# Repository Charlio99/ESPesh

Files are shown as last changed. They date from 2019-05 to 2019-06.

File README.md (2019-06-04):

# ESPesh







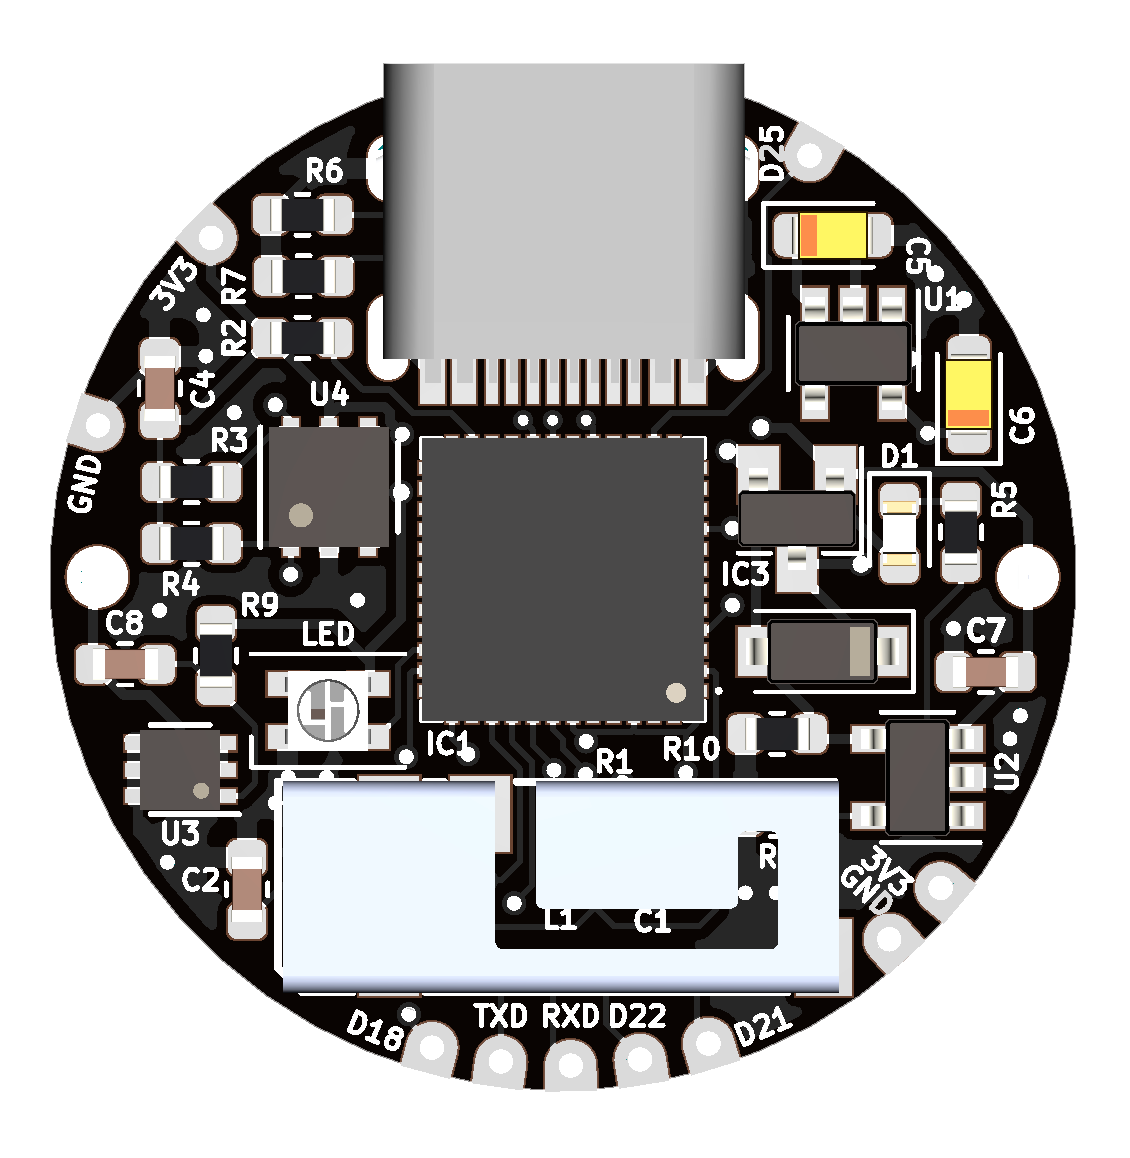
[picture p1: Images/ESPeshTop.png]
ESPesh


ESPesh is a super tiny board designed for IoT applications.
My plan is to use it as a BLE Mesh for IoT sensors and switches, because with BLE the power consumption is less than 1mA.

# Features

  - ESP32-PICO-D4
  - Low power design (LDO, removed unnecessary components)
  - Only one inch PCB
  - USB C (only for power, not programming)
  - LiPO battery (with charger and voltage protections)
  - Some GPIOs exposed (I2C included)

### BOM

I mainly use JLCPCB and LCSC for PCB and components.

| Component | Quantity | Link | Price |
| --- | --- | --- | --- |
| ESP32-PICO-D4 | 1 | https://lcsc.com/product-detail/Others_Espressif-Systems-ESP32-PICO-D4_C193707.html | $4.34 |
| PRO-OB-440 | 1 | https://www.digikey.es/product-detail/es/proant-ab/PRO-OB-440/1532-1001-1-ND/4895684 | $0.95 |
| LIR2450 | 1 | https://es.aliexpress.com/item/32853897751.html | $2.76 |
| 0.1uF | 3 | https://lcsc.com/product-detail/Multilayer-Ceramic-Capacitors-MLCC-SMD-SMT_SAMSUNG_CL10B104KA8NNNC_100nF-104-10-25V_C1590.html | $0.29 |
| 2.7pF | 1 | https://lcsc.com/product-detail/Multilayer-Ceramic-Capacitors-MLCC-SMD-SMT_SAMSUNG_CL10C2R7CB8NNNC_2-7pF-2R7-0-25pF-50V_C16149.html | $0.61 |
| 4.7pF | 1 | https://lcsc.com/product-detail/Multilayer-Ceramic-Capacitors-MLCC-SMD-SMT_SAMSUNG_CL10C4R7CB8NNNC_4-7pF-4R7-0-25pF-50V_C57140.html | $0.405 |
| 10uF Tantalum | 2 | https://lcsc.com/product-detail/Tantalum-Capacitors_AVX_TAJA106K010RNJ_10uF-106-10-10V_C7177.html | $0.2386 |
| 10uF | 1 | https://lcsc.com/product-detail/Multilayer-Ceramic-Capacitors-MLCC-SMD-SMT_SAMSUNG_CL10A106KP8NNNC_10uF-106-10-10V_C19702.html | $0.52 |
| LED 0603 | 1 | https://lcsc.com/product-detail/Light-Emitting-Diodes-LED_Red-LED-SMDLED-80-100mcd_C84263.html | $0.64 |
| SK6805 | 1 | https://es.aliexpress.com/item/32903030496.html | $3.23 |
| MBR0520 | 1 | https://lcsc.com/product-detail/Schottky-Barrier-Diodes-SBD_Changjiang-Electronics-Tech-CJ-MBR0520_C77335.html | $0.56 |
| FDN340P | 1 | https://lcsc.com/product-detail/MOSFET_ON-Semicon_FDN340P_ON-Semicon-ON-FDN340P_C75469.html | $0.1241 |
| 1.6nH | 1 | https://lcsc.com/product-detail/Others_GOOGLL-GGW0603UC1N6KGT_C343064.html | $0.0310 |
| 10K | 2 | https://lcsc.com/product-detail/Chip-Resistor-Surface-Mount_Uniroyal-Elec-0603WAF1002T5E_C25804.html | $0.1 |
| 6.8K | 2 | https://lcsc.com/product-detail/Chip-Resistor-Surface-Mount_Uniroyal-Elec-0603WAF6801T5E_C23212.html | $0.1 |
| 2K | 1 | https://lcsc.com/product-detail/Chip-Resistor-Surface-Mount_Uniroyal-Elec-0603WAF2001T5E_C22975.html | $0.1 |
| 5K1 | 2 | https://lcsc.com/product-detail/Chip-Resistor-Surface-Mount_Uniroyal-Elec-0603WAF5101T5E_C23186.html | $0.1 |
| 43K | 1 | https://lcsc.com/product-detail/Chip-Resistor-Surface-Mount_Uniroyal-Elec-0603WAF4302T5E_C23172.html | $0.11 |
| 100R | 1 | https://lcsc.com/product-detail/Chip-Resistor-Surface-Mount_Uniroyal-Elec-0603WAF1000T5E_C22775.html | $0.11 |
| 100K | 1 | https://lcsc.com/product-detail/Chip-Resistor-Surface-Mount_Uniroyal-Elec-0603WAF1003T5E_C25803.html | $0.1 |
| SPX3819M5-L-3-3 | 1 | https://lcsc.com/product-detail/Low-Dropout-Regulators-LDO_EXAR_SPX3819M5-L-3-3-TR_SPX3819M5-L-3-3-TR_C9055.html | $0.1225 |
| SL4054ST25P | 1 | https://lcsc.com/product-detail/Others_TECHFUSE-SL4054ST25P_C258510.html | $0.509 |
| XB6566H0 | 1 | https://lcsc.com/product-detail/Others_XB6566H0_C190847.html | $0.1734 |
| HDC1080 | 1 | https://lcsc.com/product-detail/Humidity-Moisture-Sensors_TI_HDC1080DMBR_HDC1080DMBR_C82227.html | $1.1216 |
| HRO-TYPE-C-31-M-12 | 1 | https://lcsc.com/product-detail/USB-Type-C_Korean-Hroparts-Elec-TYPE-C-31-M-12_C165948.html | $0.3882 |
| | | **TOTAL** | **$17.7334**|

Take in account that some components must be ordered in larger batches that the quantity needed (for example: SK6805: we need only one, but min order is 10).

### Todos

 - Wiki
 - Test the board
 - Sell it on Tindie so I can keep developing such tiny boards

### License

Creative Commons Attribution-NonCommercial-ShareAlike 4.0 International Public License

**Open Source, Hell Yeah!**

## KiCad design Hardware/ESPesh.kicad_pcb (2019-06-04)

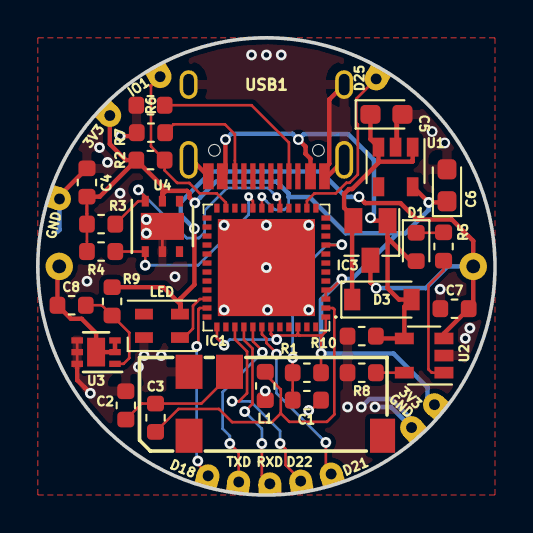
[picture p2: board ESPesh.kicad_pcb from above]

Board: 2 copper layers, 25.4 x 25.4 mm, 42 parts (1 on the bottom side), 25 nets.

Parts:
3V3, 3V3#2: Conn_01x01; RoundPadPassthrough
ANT1: PRO-OB-440; PRO-OB-440_1
BATT1: LIR2450
C1, C4, C8: 0.1uF; C_0603_1608Metric
C2: 2.7pF; C_0603_1608Metric
C3: 4.7pF; C_0603_1608Metric
C5, C6: 10uF; CP_EIA-2012-12_Kemet-R
C7: 10uF; C_0603_1608Metric
D1: LED; LED_0603_1608Metric
D3: MBR0520; D_SOD-123
D18, D21, D22, D25: Conn_01x01; RoundPadPassthrough
GND: Conn_01x01; RoundPadPassthrough
GND#2: Conn_01x01; RoundPadPassthrough
IC1: ESP32-PICO-D4; ESP32PICOD4
IC3: FDN340P; SuperSOT-3
IO1: Conn_01x01; RoundPadPassthrough
L1: 1.6nH; L_0603_1608Metric
LED: SK6805; LED_SK6805_PLCC4_2.4x2.7mm_P1.3mm
R1, R2: 10K; R_0603_1608Metric
R3, R4: 6.8K; R_0603_1608Metric
R5: 2K; R_0603_1608Metric
R6, R7: 5K1; R_0603_1608Metric
R8: 43K; R_0603_1608Metric
R9: 100; R_0603_1608Metric
R10: 100K; R_0603_1608Metric
RXD: Conn_01x01; RoundPadPassthrough
TXD: Conn_01x01; RoundPadPassthrough
U1: SPX3819M5-L-3-3; SOT-23-5
U2: SL4054ST25P; SOT-23-5
U3: XB6566H0; DFN-6-1EP_2x2mm_P0.65mm_EP1x1.6mm
U4: HDC1080; Texas_PWSON-N6
USB1: HRO-TYPE-C-31-M-12; HRO-TYPE-C-31-M-12-Assembly

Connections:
+3V3: 3V3.1, 3V3#2.1, C4.2, C6.1, IC1.1, IC1.3, IC1.4, IC1.19, IC1.37, IC1.43, IC1.46, R1.2, R2.1, R3.1, R4.1, U1.5, U4.5
+BATT: BATT1.1, C7.1, IC3.1, LED.4, R9.2, U2.3
-BATT: BATT1.2, C8.2, U3.2, U3.3, U3.7
/EN: C1.1, IC1.9, R1.1
/IO0: IC1.23, IO1.1, R2.2
/IO18: D18.1, IC1.35
/IO21: D21.1, IC1.42
/IO22: D22.1, IC1.39
/IO25: D25.1, IC1.14
/LED: IC1.34, LED.3
/RXD: IC1.40, RXD.1
/SCL: IC1.17, R3.2, U4.6
/SDA: IC1.20, R4.2, U4.1
/TXD: IC1.41, TXD.1
GND: ANT1.1, C1.2, C2.2, C4.1, C5.2, C6.2, C7.2, GND.1, GND#2.1, IC1.49, L1.1, LED.2, R6.2, R7.2, R8.1, R10.2, U1.2, U2.2, U3.4, U3.5, U3.6, U4.2, U4.7, USB1.1, USB1.12, USB1.13
unnamed: ANT1.2, C2.1, C3.1
unnamed: C3.2, IC1.2, L1.2
unnamed: C8.1, R9.1, U3.1
unnamed: D1.1, R5.1
unnamed: R5.2, U2.1
unnamed: R6.1, USB1.4
unnamed: R7.1, USB1.10
unnamed: R8.2, U2.5
VCC: D1.2, D3.2, IC3.2, R10.1, U2.4, USB1.2, USB1.11
VDD: C5.1, D3.1, IC3.3, U1.1, U1.3

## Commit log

2019-05-07 First revision uploaded, NOT TESTED!
    [ESPesh.kicad_pcb, ESPesh.sch]
2019-05-07 Added PCB images
2019-05-07 Added GND pad
    [ESPesh.kicad_pcb, ESPesh.sch]
2019-05-07 Updated top PCB image
2019-05-07 rev0.2: fixed ESP32 footprint missmatch
    [ESPesh-B.Cu.gbr, ESPesh-B.Mask.gbr, ESPesh-B.Paste.gbr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]
2019-05-08 rev0.3 and panelized gerbers
    [ESPesh-B.Cu.gbr, ESPesh-B.Mask.gbr, ESPesh-B.Paste.gbr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]
2019-06-04 #1 Minor fixes and rev0.3 tested (antenna not tested yet)
    [ESPesh-B.Cu.gbr, ESPesh-B.Mask.gbr, ESPesh-B.Paste.gbr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]

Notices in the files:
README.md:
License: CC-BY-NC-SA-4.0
